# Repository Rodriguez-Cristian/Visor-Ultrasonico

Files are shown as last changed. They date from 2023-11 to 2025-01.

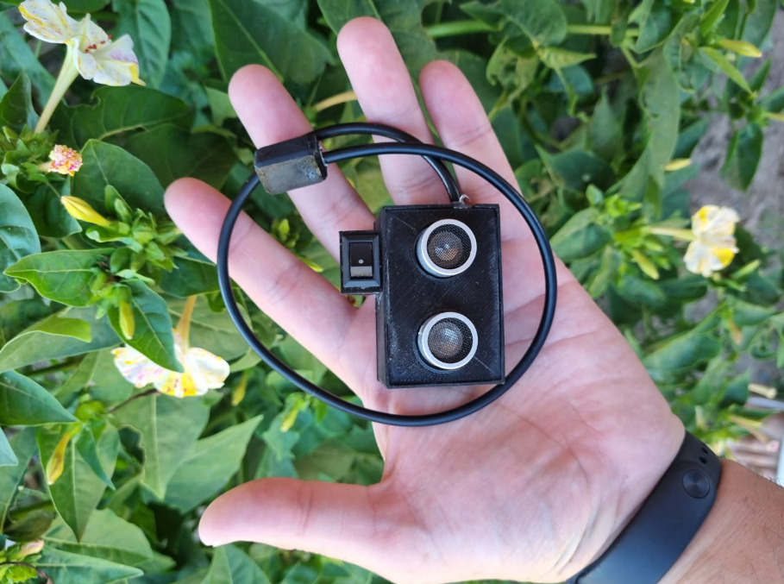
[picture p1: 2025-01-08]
visor.png

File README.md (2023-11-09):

# Visor-Ultrasonico
Este proyecto lo cree en el año 2015 y en 2017 obtuve un reconocimiento nacional e internarcional en Tecnopolis, en ese momento el desarrolo fue mas complejo, pero hoy les dejo el armando con arduino, para que todo alquel que quiera fabricarlo lo pueda hacer!

https://viapais.com.ar/santa-rosa/2075091-un-joven-emprendedor-de-santa-rosa-desarrollo-un-visor-ultrasonico-para-personas-con-disminucion-visual/

https://youtu.be/dXAR2UKQNHc   -> Video Donde Explico que lo Dono!

https://youtube.com/shorts/26Cykkt0PCE -> Video Probandolo 
https://youtube.com/shorts/yFM9jB2ltoc -> Video Probandolo 2

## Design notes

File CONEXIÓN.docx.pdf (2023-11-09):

# CONEXIÓN

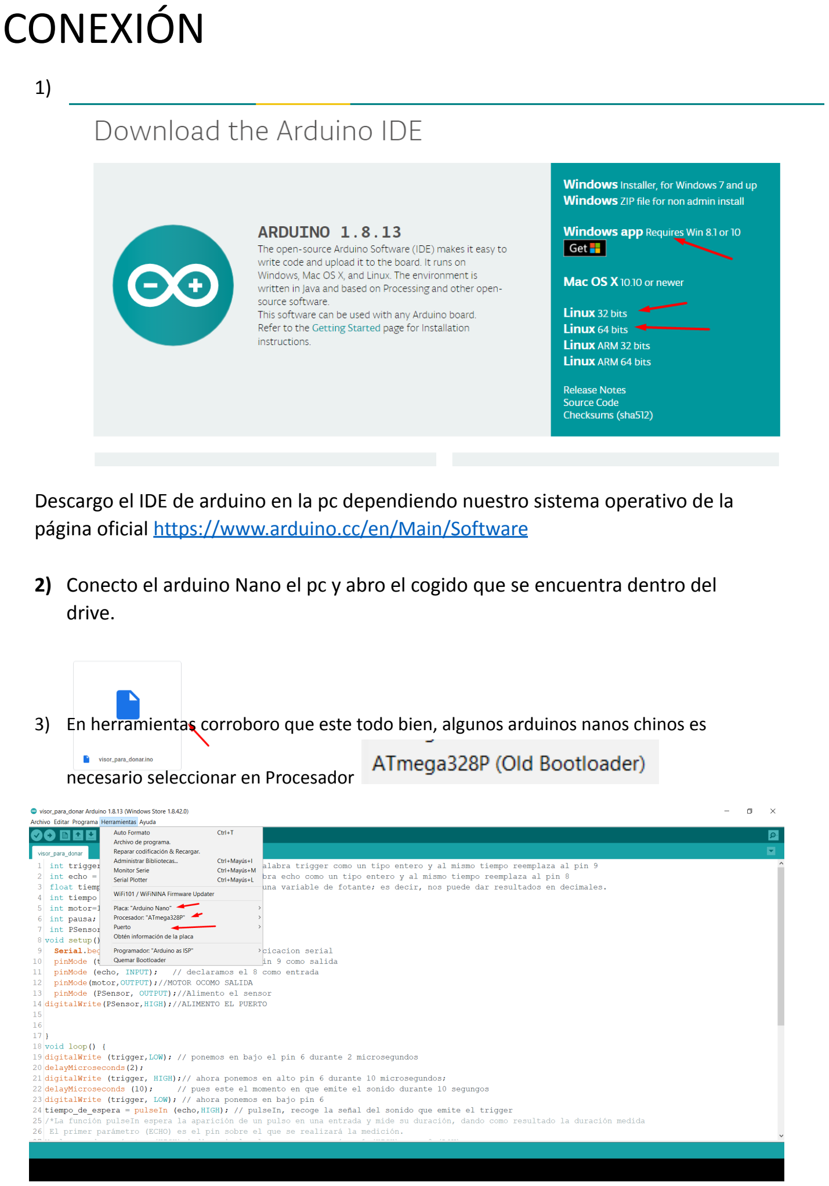
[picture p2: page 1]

1)

Descargo el IDE de arduino en la pc dependiendo nuestro sistema operativo de la página oficial https://www.arduino.cc/en/Main/Software

2) Conecto el arduino Nano el pc y abro el cogido que se encuentra dentro del drive.
3) En herramientas corroboro que este todo bien, algunos arduinos nanos chinos es

necesario seleccionar en Procesador

4) Compilarlo haciendo clic en la flecha
5) Desconectar y comenzar a conectar de este modo como indico en la imagen

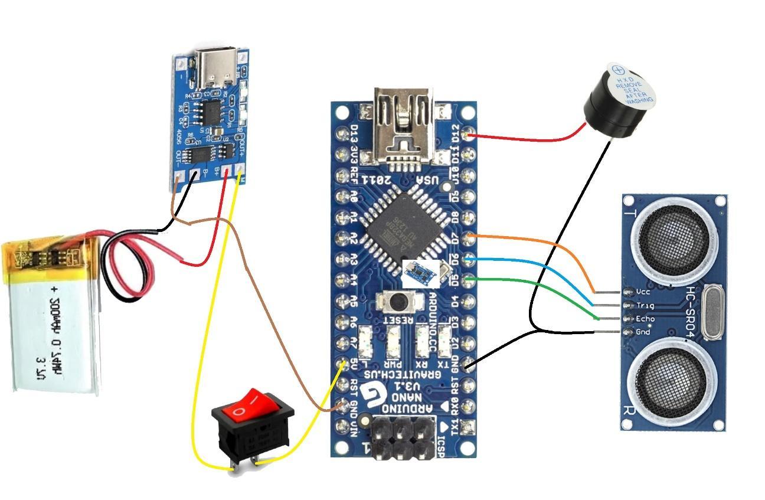
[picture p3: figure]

BATERIA POSITIVO al (B+) Negativo al (B-) del módulo de carga
(OUT – ) del modulo de carga al (GND) del arduino Nano
(OUT +) del modulo de carga a cualquiera a la primer chapita de la tecla Chapita restante de la tecla al (5v) del arduino nano
(+) del buzzer al (D12) del arduino Nano
(-) del buzzer al (GND) del Arduino Nano
(Vcc) del ultrasónico al (D7) del Arduino Nano (Trig) del ultrasónico al (D6) del Arduino Nano (Echo) del ultrasónico al (D5) del Arduino Nano (Gnd) del ultrasónico al (GND) del arduino Nano

Cristian Rodriguez
coliitohr@gmail.com
@coliitoh – Instagram
@coliitohr – Twitter

Santa Rosa – La Pampa

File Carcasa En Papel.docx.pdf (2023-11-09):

Lo Naranja va hueco

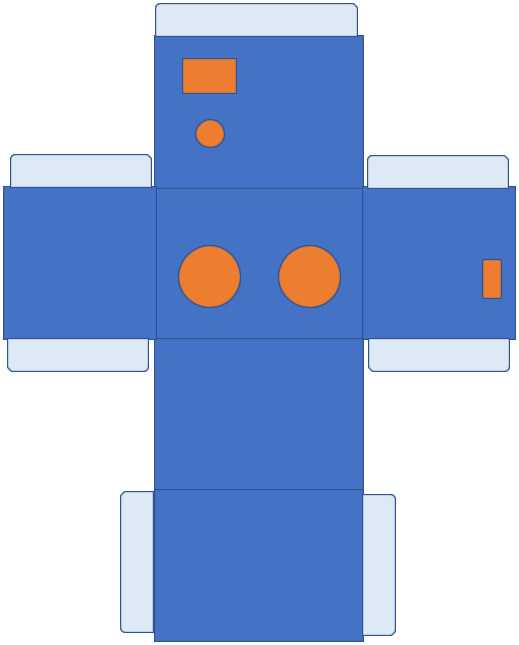
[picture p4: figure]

Cristian Rodriguez
coliitohr@gmail.com
@coliitoh – Instagram
@coliitohr – Twitter
Santa Rosa – La Pampa

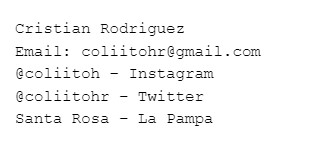
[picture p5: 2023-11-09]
Contacto.jpg

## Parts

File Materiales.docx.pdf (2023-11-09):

# Lista de Materiales

*Impresión 3D o Carcasa de cartón usando la maqueta subida.

*15cm de elástico

*Sensor Ultrasónico (

https://articulo.mercadolibre.com.ar/MLA-838740547-sensor-ultrasonido-hc-sr04-para-arduino-pic-robotica-sgk-_JM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 6b-98e0-e7a01e62218d) (https://articulo.mercadolibre.com.ar/MLA-838740547-sensor-ultrasonido-hc-sr04-para-arduino-pic-robotica-sgk-_JM)

*Arduino Nano

(https://articulo.mercadolibre.com.ar/MLA-788263833-arduino-nano-v30-atmega328-compatible-usb-con-ch340-_JM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 4e6-a9e3-44e59f9daa2b) (https://articulo.mercadolibre.com.ar/MLA-788263833-arduino-nano-v30-atmega328-compatible-usb-con-ch340-_JM)

*Buzzer o vibrador de celular

(https://articulo.mercadolibre.com.ar/MLA-769464974-buzzer-activo-5v-arduino-pic-raspberry-electronica-ubot-_JM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 7-8fd4-8d93185a0678) (https://articulo.mercadolibre.com.ar/MLA-769464974-buzzer-activo-5v-arduino-pic-raspberry-electronica-ubot-_JM)

(https://articulo.mercadolibre.com.ar/MLA-876131137-flex-vibrador-samsung-j1-ace-j111m-100-original-outlet-_JM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 b-b10d-2f6bb2712e86) (https://articulo.mercadolibre.com.ar/MLA-876131137-flex-vibrador-samsung-j1-ace-j111m-100-original-outlet-_JM)

*Módulo de carga

(https://articulo.mercadolibre.com.ar/MLA-788844425-modulo-tp4056-carga-bateria-litio-con-proteccion-usb-tipo-c-_JM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 -4059-b5e1-8b3d6ad51eaa) (https://articulo.mercadolibre.com.ar/MLA-788844425-modulo-tp4056-carga-bateria-litio-con-proteccion-usb-tipo-c-_JM)

*Batería

(https://articulo.mercadolibre.com.ar/MLA-835896948-bateria-litio-polimero-lipo-37v-200mah-drone-camaras-lanus-_JM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 -46f9-904a-6a7b9c357ad6) (https://articulo.mercadolibre.com.ar/MLA-835896948-bateria-litio-polimero-lipo-37v-200mah-drone-camaras-lanus-_JM)

*Tecla on/off

(https://articulo.mercadolibre.com.ar/MLA-817288152-llave-tecla-2-patas-on-off-3a-250v-214-x-15mm-_JM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) (https://articulo.mercadolibre.com.ar/MLA-817288152-llave-tecla-2-patas-on-off-3a-250v-214-x-15mm-_JM)

*Soldador, Estaño y 1mtro de cable fino.

Cristian Rodriguez
coliitohr@gmail.com
@coliitoh – Instagram
@coliitohr – Twitter
Santa Rosa – La Pampa

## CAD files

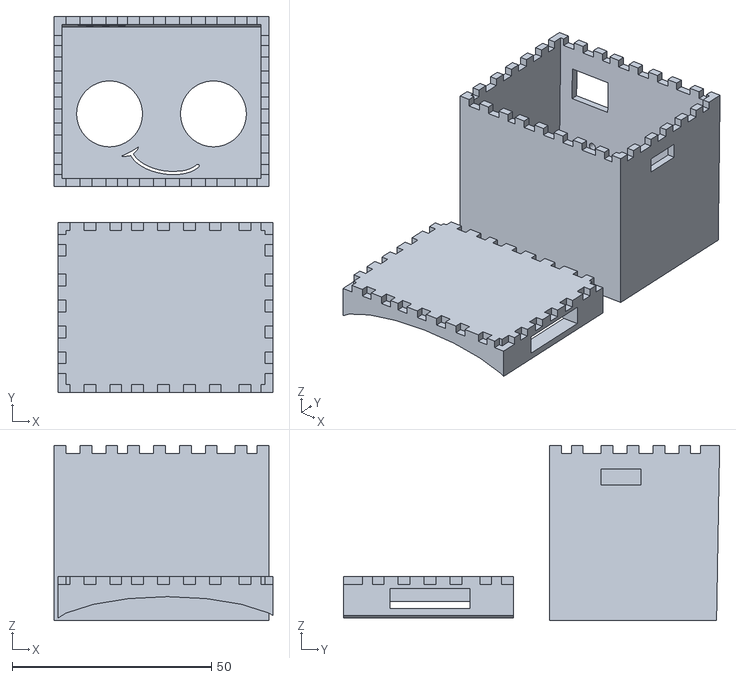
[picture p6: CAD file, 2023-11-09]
Visor Ultrasonico Diseño para 3D.stl
55.0 x 94.5 x 44.0

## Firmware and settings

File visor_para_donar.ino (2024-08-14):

 int trigger = 6;           // declaramos la palabra trigger como un tipo entero y al mismo tiempo reemplaza al pin 9
 int echo = 5;           // declaramos la palabra echo como un tipo entero y al mismo tiempo reemplaza al pin 8
 float tiempo_de_espera,distancia; // creamos una variable de fotante; es decir, nos puede dar resultados en decimales.
 int tiempo = 500;
 int motor=12;//motor o buzzer
 int pausa;
 int PSensor=7;
void setup() {
  Serial.begin (9600);   // establemos la comucicacion serial
  pinMode (trigger, OUTPUT); // declarmos el pin 9 como salida
  pinMode (echo, INPUT);   // declaramos el 8 como entrada
  pinMode(motor,OUTPUT);//MOTOR OCOMO SALIDA
  pinMode (PSensor, OUTPUT);//Alimento el sensor
digitalWrite(PSensor,HIGH);//ALIMENTO EL PUERTO
           
  
}
void loop() {
digitalWrite (trigger,LOW); // ponemos en bajo el pin 6 durante 2 microsegundos
delayMicroseconds(2);
digitalWrite (trigger, HIGH);// ahora ponemos en alto pin 6 durante 10 microsegundos;
delayMicroseconds (10);     // pues este el momento en que emite el sonido durante 10 segungos
digitalWrite (trigger, LOW); // ahora ponemos en bajo pin 6 
tiempo_de_espera = pulseIn (echo,HIGH); // pulseIn, recoge la señal del sonido que emite el trigger
/*La función pulseIn espera la aparición de un pulso en una entrada y mide su duración, dando como resultado la duración medida                   
 El primer parámetro (ECHO) es el pin sobre el que se realizará la medición.
Y el segundo parámetro (HIGH) indica si el pulso a esperar será un 1 (HIGH) o un 0 (LOW).
 */
distancia =(tiempo_de_espera/2)/29.15; // formula para hallar la distancia
Serial.print (distancia);    // imprimimos la distancia en cm
Serial.println ("cm");//CM


if(distancia < 60){//si detecta algo a 60cm activa!
  
{
   pausa = distancia * 10;//
   digitalWrite(motor, HIGH);
   delay(pausa);
} 
  digitalWrite(motor, LOW);
   delay(pausa);
}
}
